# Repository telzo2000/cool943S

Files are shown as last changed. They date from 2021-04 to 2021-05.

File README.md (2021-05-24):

# ビルドガイド（執筆中）
https://github.com/telzo2000/cool943S/blob/main/buildguide_for_cool943S.md
<br>

# cool943S開発計画
☑︎アクリルケースの設計<br>
☑︎ファームウェアの用意<br>
<br>

# 発注ガーバーファイル名
Ver.1　gbrcool943S20210212.zip,cool943Scasedesigntop.zip,cool943Scasedesignbottom.zip　<br>
Ver.1.1 gbrcool943S20210314.zip <br>
<br>

# cool943S開発に至った経緯

cool943Sは、m.ki設計の自作キーボードです。cool836Aの次の自作キーボードとして、三桁の数字の左はじめに９が付きます。その次の二桁には、採用されたキー数として43と付きます。末尾のSはSplit（分割型）を意味しています。「coolな９番目の43キーある分割型キーボード」となります。<br>
構成はPCBを、いつも便利なSU120で作っています。ケースは全体を覆うようにMDF材を塗装しています。安価な材料としてMDFは優秀です。底面は内部が見えるように、アクリルプレート（スモークガラスのようなもの）を使っています。これらの構成は、これまでキーボードを自作した経験から選択したものであり、一般的な自作キーボードの作り方ではないかもしれません。<br>
cool943S開発の目的は、アドベントカレンダー2020に記事を投稿しようということから始まりました。<br>
そのため、これまで自分が挑戦したことがないものを作ろうと思い、40％の分割型キーボードを選択しました。nomu30を購入して30％キーボードの潔さに影響を受けて、自分でも令和2年上半期に30％キーボードMyFirstMini（34キー）を作りました。この際、SU120を初めて使いました。
MyFirstMiniはnomu30を常用した自分に、ちょっと困った句読点記号のキーを独立して配置しました。nomu30ではレイヤーキーとして使われている句読点記号キーは、日本語入力が主体の私にはちょっと利便性が抑えられました。
その後、購入したCaravelle bleの余剰パーツを利用したCarabellionを作り、SU120の使い方や、木製ケースの組み合わせ方を経験しました。
Carabellionと並行して、格子配列のcool635も開発しました。cool635は35キーの30％キーボードでPro microの配置を考えてキーレイアウトをしました。その後、配線処理に苦労して、ポリウレタン銅線から、シリコンケーブル線に変更するきっかけとなりました。cool635によって、私にとって10列で構成されるキーボードはちょっと使い勝手が難しいこともわかりました。
特に、Pキーの左隣にはBSキーが欲しいことがわかりました。<br>
ここまで作っていくと、30％キーボードでだいたい、問題はないことがわかりました。しかし、矢印キーや数字キーがあったら、やはり便利だろうと思い、30％キーボードのレイアウトに、矢印キーと数字キーを加えた構成で、cool735を開発しました。ただ、cool735は悪くないのですが、やや大きくなり持ち運ぶという用途には向かないキーボードです。常用できないのではしかたがないので、作ってみたけど、お蔵入りの品物となりました。Carabellionも同様に、お蔵入りしています。原点回帰というわけではありませんが、MyFirstMiniの延長上に、30％で使いやすいキーボード、余り肩を狭めない配列としてアリス配列を採用する、というコンセプトから、cool836Aを開発しました。<br>
cool836Aについては、cool836Aの[README](https://github.com/telzo2000/cool836A/blob/master/README.md)に詳しく記録してあります。<br>
cool836Aの欠点は、キー数です。持ち運びを考えたとき、あの大きさは有利であり、キーレイアウトは疲れを軽減すると思います。ただ、あれ以上のキー数を求めたとき、40％のAlice配列のキーボードが必要となります。ただ、それは大型化を招き、結果的に、一般的なAlice配列のキーボード（60％や65％）に帰結すると思います。私の中では40％のAlice配列は持ち運び用途としては大きい印象です。その大きさでAlice配列を求めるのであれば、分割キーボードで十分と考えます。ここからcool943Sのコンセプトは決まりました。<br>
Alice配列ではないけど、肩を狭めなくても良い分割型、そして40％キーボードとなりました。<br>
課題はただ一つ、私自身が分割型キーボードを開発した経験がないことでした。これまで作ってキーボードでは、ファームウェアの開発はせずにすみました。Keyboard Firmware Builderというサイトが、初心者の私の味方でした。しかし、このサイトでは多分、分割型キーボードのファームウェアは作れないのです。（私が使い始めた頃は、LED関係の機能もできませんでしたが、令和２年秋ごろにはできるようになりました）<br>
結果として、私はこれまで回避してきたqmk_firmwareの勉強をする羽目となりました。私が普段使っているのはマックです。先人たちの情報をネットで探しながら、やってみましたが、できません。homebrewあたりからつまずきました。pythonがいろいろと邪魔をして、先へ進めませんでした。<br>
我が家にあるMacOS以外のOSを持つコンピュータは、ラズパイとGPD Pocket2でした。ウインドウズはさらにわからなかったので、ラズパイでなんとかすることとしました。ネットで「ラズパイ」「QMK」で検索かけたら、いくつかサイトがヒットしました。それらを順に見て、バタバタしていたら、12月末、ラズパイでqmk_firmwareが使えるようになりました。そこでまず、KEYBOARD FIRMWARE BUILDERでファームウェアを作って動かしていていたcool836Aを元にして、qmk_firmwareで作り直すことに成功しました。すぐにできたのではなく、他の人のファームウェアを真似して出来上がったものです。その経験を元にして、cool943Sのファームウェアを作り始めました。元にしたのは、keebioのfourierとRecompile Keyさんのcocoa40です。元々、この２つの分割40％キーボードがcool943Sの目指した姿だったのです。実際のところ、キー数は少なくしてあります。私自身、30％キーボードを常用しています。キー数が少なくても問題はありません。cool943Sは40%のアリス配列の代わりに、より使いやすい配列として分割キーボードを選択して生まれたものです。fourierやcocoa40を入手できていたならば、自分で作ることはなかったと思います。今のところ、cool943Sは私にとってのエンドゲームかもしれません。<br>
令和元年に購入して以来、職場に持ち込み、1年と少しの期間使用していたChoco60に代わって、cool943Sを職場に持ち込みました。職場で使用して問題がなければ、自宅用にもう一つ、作成しようと考えています。（とりあえず、ここまで　令和３年１月27日）<br>
令和3年2月12日にelecrowへkicadで設計したcool943Sを発注しました。アクリルケースも一緒に発注しました。ただ春節絡みで届くのが遅くなりました。<br>
2月末にelecrowから発注していたPCBやアクリルが届きました。しかし検品の段階で、アクリルは注文通りでないことがわかり、メールで修正するように伝えました。
届いた部品のうち、ミドルプレートが注文通りでなく、左右と長さの違う形状で４種類のミドルプレートを注文していたが、同じ形状のものでした。
多分、担当者がよく見ずに、似ていると思い込んで、同じものを複数枚作成したと思われる。
これは相手側のミスであったため、さらに数日後、正しいものが届くまで完成が待たされた。　<br>
実際に作ってみたときにわかった問題点は次の通りである。<br>
①三行目左端のシフトキー部分のスイッチ位置のミス。これについてはkicadで修正した。<br>
②通信に関するピンサインのミス。今後、kicadで修正した。<br>
③混線が発生している可能性。原因がわかっていない。kicadで確認する。②の修正により解決すると思われる。<br>
④アクリルで作ったスイッチプレートが割れやすいこと、スイッチを装着しづらいこと。スイッチプレートをPCBと同じ素材で作るか、スイッチプレートとPCBの間に３mmのアクリルプレートを挟むか、３mmスペーサーを付け加えるか、が思いつく対応策。<br>
上記の①～④を修正したPCBをVer.1.1とした。３月14日elecrowに発注。これは、以前アクリルで作成したスイッチプレートをPCBと同じFR-4素材で作成した。結果として、Ver.1のPCBとスイッチプレートと差し替えることで、Ver.1の資産を継続して使えるようにした。これにより問題なく活用できるようであれば、全部で５セット分ある部品のうち、すでに作成した１セットと、予備用に１セットを残して、他３セットを頒布しようと考えている。これはcool844ほど反響がないと思っているので、それ以上の追加発注は考えていない。<br>
3月末に、ver1.1を組んでみた。FR-4で作ったスイッチプレートはアクリルで作ったものに比べて、剛性感が高かった。強度の心配はなくなった。elecrowに発注した部品は一箇所、ミスがわかり、後日修正されたものが届くこととなった。誰かが春節すぎると技術が低下すると言っていた。そうなのかもしれない。でも、時間がかかるが、修正版が届くのでまあ、よい。このあと、LEDテープを貼り付けて、LEDの点灯もできた。キーレイアウト編集のために、REMAPが使えるようにした。これで初心者でもキーレイアウトの編集が容易になる。<br>
また、４月になり、修正されたスイッチプレートelecrowから届いたので、２台目のcool943Sを作成した。
これはキースイッチをT3 タンジェリンで組み、今年になって職場に持っていったSU120版cool943Sと交換した。
kicad版cool943Sを２台作り、わかったことは、発注したアクリルは２mmであるが、実際はやや２mmより薄いのであろう。
そのため、ミドルプレートに４枚アクリル板を積層し、固定するために入れた８mmスペーサーがやや頭が出ている状態である。
これについては、７mmスペーサーを発注して、対応してみようと考えている。<br>
④の問題点の解決策として、PCBと同じFR-4でスイッチプレートを作った。
そのため、アクリルでのスイッチプレートは不要である。
しかし、アクリルのスイッチプレートを作っても作らなくても、使用するアクリル板の大きさは変わらないことがわかった。
結果として、被ってしまうが、①の問題点と、割れやすい箇所のやや広く作ったアクリル板のスイッチプレートの修正をした。<br>
アクリルケースについては、４月１８日時点では発注しない。最初の３台の頒布をして、その後、まだ欲しい人がいるようであれば、その時発注しようと思う。<br>

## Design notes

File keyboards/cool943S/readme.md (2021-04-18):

# cool943S

cool943S

*A short description of the keyboard/project*

* Keyboard Maintainer: [m.ki](https://github.com/telzo2000)
* Hardware Supported: *The PCBs, controllers supported*
* Hardware Availability: *Links to where you can find this hardware*

Make example for this keyboard (after setting up your build environment):

    make cool943S:default

Flashing example for this keyboard:

    make cool943S:default:flash

See the [build environment setup](https://docs.qmk.fm/#/getting_started_build_tools) and the [make instructions](https://docs.qmk.fm/#/getting_started_make_guide) for more information. Brand new to QMK? Start with our [Complete Newbs Guide](https://docs.qmk.fm/#/newbs).

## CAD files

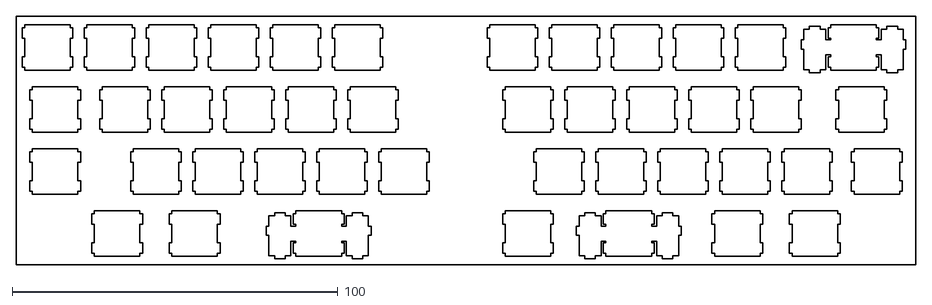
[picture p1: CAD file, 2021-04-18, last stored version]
a34305ff9da19b46c51bc98033632a78f7ae009a_switch.dxf
276.2 x 76.2

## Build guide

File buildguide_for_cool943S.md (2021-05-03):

# cool943S　ビルドガイド
## 特徴
<br>
・cool943Sは、m.kiが設計した40％分割キーボードです。
40％分割キーボードはあまり多く流通していません。自分用に欲しいと思い、これまで自作したcool836A、cool844等得た経験を生かして設計しました<br>
・入力に必要なキー以外を省略することでコンパクトな形にしました。<br>
・pro microの配置位置を工夫することで、高さを抑えました。
私はcool943Sを使用する際、パームレストは不要となりました。<br>
・トップカバープレートにより、pro microに置き換えて、将来的にble microと電池ケースを使用することも構造的に可能となっています。
・ファームウェアは、youichiro氏の開発したREMAPにて、キーレイアウトの編集が簡単にできます。
QMK_FIRMWAREの知識が無くても大丈夫です。<br>
・サウンドテストの様子<br>
https://twitter.com/0002ozlet/status/1381212035929665536
<br>

## 1　部品の確認
次の部品で構成されています。<br>
１　　PCB　左右それぞれ１枚<br>
２　　スイッチプレート　左右それぞれ１枚<br>
３　　トップカバープレート　左右それぞれ１枚<br>
４　　ミドルプレート　左右それぞれ４枚<br>
５　　ボトムプレート　左右それぞれ１枚<br>
６　　チルトプレート　左右それぞれ２枚<br>
７　　M２ネジ（４ｍｍ８本、８ｍｍ12本）<br>
８　　M２ナット　６個<br>
９　　M２スペーサー８ｍｍ六角形タイプ　10個<br>
１０　Pro micro　２個<br>
１１　TRRSジャック　２個<br>
１２　タクトスイッチ　２個<br>
１３　TRRSケーブル １本<br>
１４　MXソケット　43個<br>
１５　ダイオード　43個<br>
１６　LEDテープ　２枚<br>
１７　スタビライザー（２Uサイズ）　３個<br>
１８　キースイッチ　43個<br>
１９　キーキャップセット　※任意<br>
２０　USBケーブル（Pro microの端子に準拠したもの）<br>
２１　ゴム足（クッションゴム、ウレタンパッドなど）<br>
<br>
部品のうち、<br>
１〜６はキットに同封されています。<br>
７・８・２１はDIY店でも購入可能です。<br>
９は遊舎工房またはWILCOでネット通販可能です。４のミドルプレートの厚さについてアクリルの精度に課題があり、隙間なく重ねたとき、M２スペーサー８mmがやや出てしまうことがわかりました。気になる方は、M２スペーサー７mm六角形タイプ８個も用意することを勧めます。<br>
１０〜２１は遊舎工房、TALP KEYBOARDS、KOCHI KEYBOARDで店頭もしくはネット通販で購入可能です。<br>
これらの部品を、すべてを同封してキット化することできないため、購入者が別途に購入する必要があります。
そのため、私自身が設計、発注した部品１〜６のみ、頒布する形を取りました。
それにより、私自身、部品等を余剰に在庫する必要もなく、購入者自身も選択肢のある部品等を自分の好みで購入することができ、お互いにとって、良い形になると思います。

<br><br>

部品の写真（１・２）
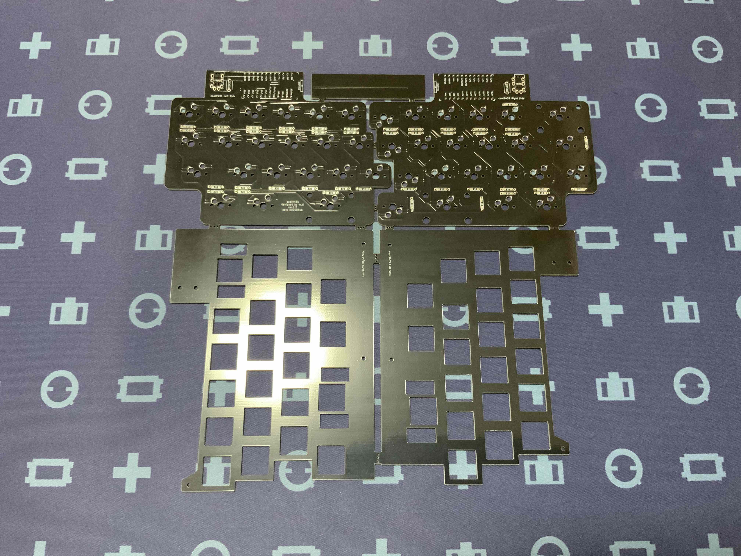
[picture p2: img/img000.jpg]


部品の写真（３・４・５・６）
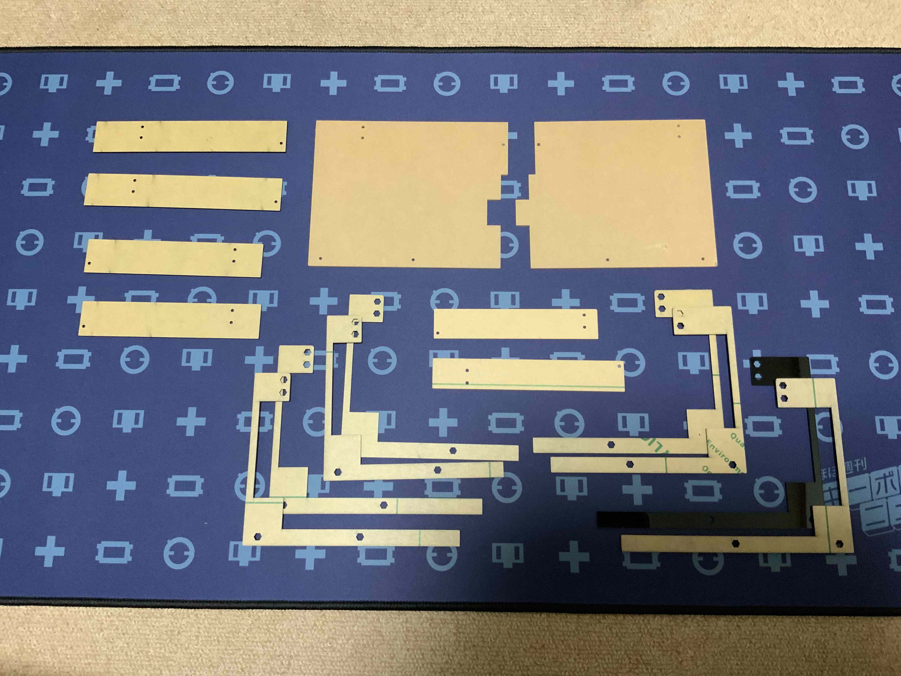
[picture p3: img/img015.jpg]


## ２　ファームウェアについて
cool943Sはyouichiro氏の開発したREMAPにて、キーレイアウトの編集ができます。<br>
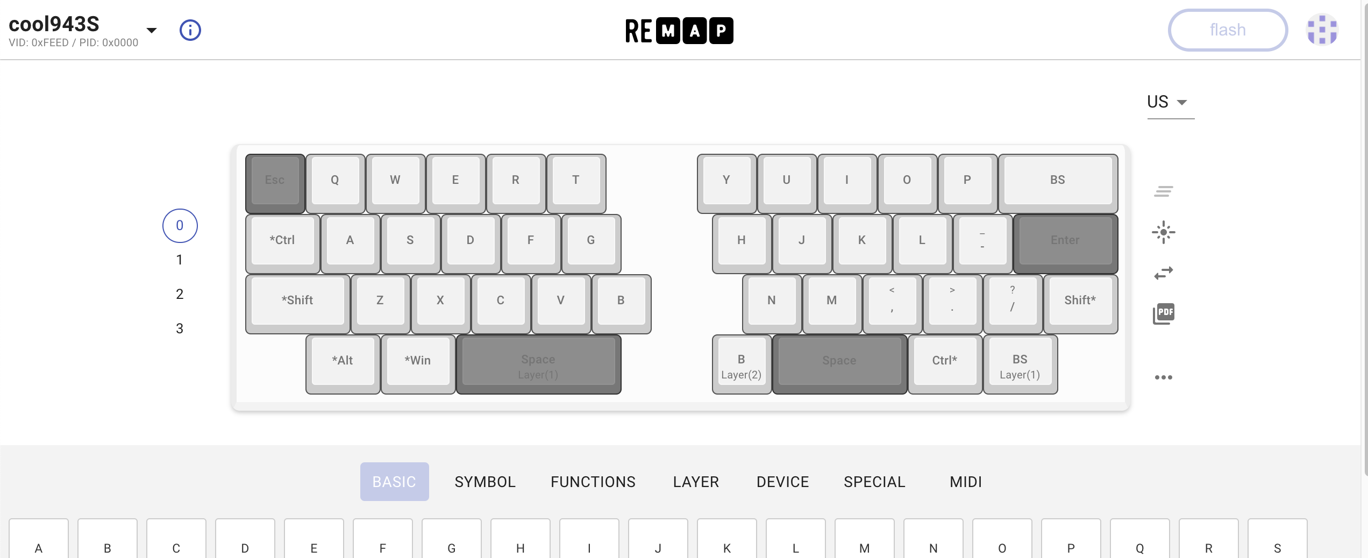
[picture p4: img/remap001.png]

次の[Hexファイル](https://github.com/telzo2000/cool943S/blob/main/cool943S_via.hex)をダウンロードしてください。そして、QMK TOOLBOXにてPro microへの書き込みをしてください。<br>
REMAPで作業するための[Jsonファイル](https://github.com/telzo2000/cool943S/blob/main/cool943S_remap.json)はこちらにあります。<br>
chromeを起動して、「REMAP」と検索し、REMAPのサイトへアクセスしてください。<br>
（令和3年５月３日追記）REMAPに正式対応しました。
申し込みから承認までの素早い対応に感謝します。<br>
（追記終了）<br>

## ３　色塗り
スイッチプレート及びPCBの側面を黒色マジックで塗ってください。cool943Sは側面が黒色アクリルプレートを使用していますので、スイッチプレート及びPCBの側面も同じ黒色のほうが格好良くなります。<br>
## ４　ダイオードのハンダ付け
ダイオードの足を曲げて取り付けて、ハンダ付けをします。ダイオードの足は、下面から「diode」と印刷された部分の穴に差し込みます。短く切ったマスキングテープで固定してから、裏返して、上面に伸びたダイオードの足は切り離してください。ダイオードには極性があります。ダイオードの黒い帯がある側が「diode」の文字の後ろになるようにハンダ付けしてください。ハンダ付けに自信がない場合、フラックスを利用すると、上手にハンダ付けができます。その後、フラックスクリーナーで綺麗に拭き取ることをお勧めします。<br>
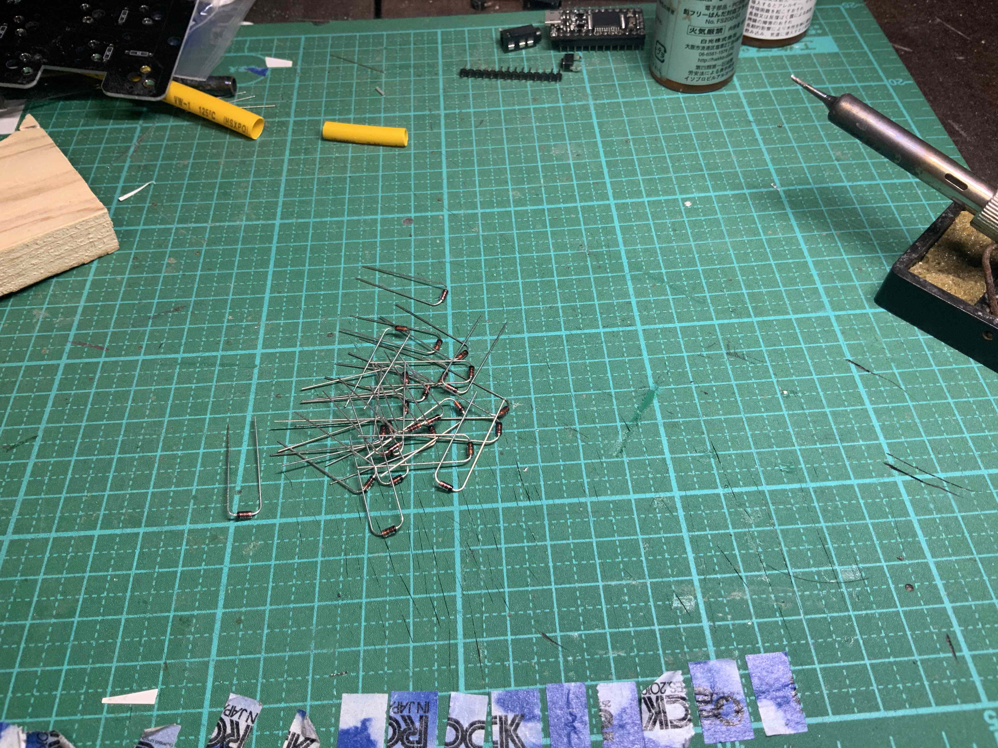
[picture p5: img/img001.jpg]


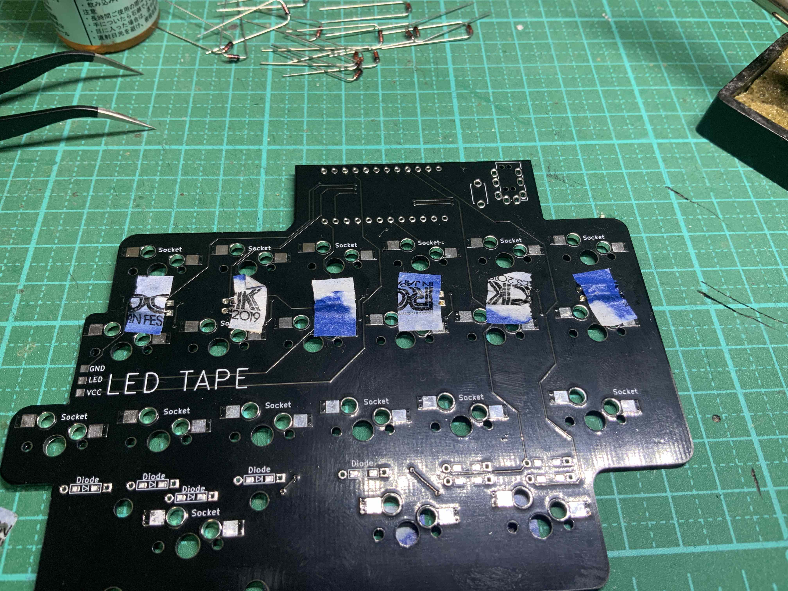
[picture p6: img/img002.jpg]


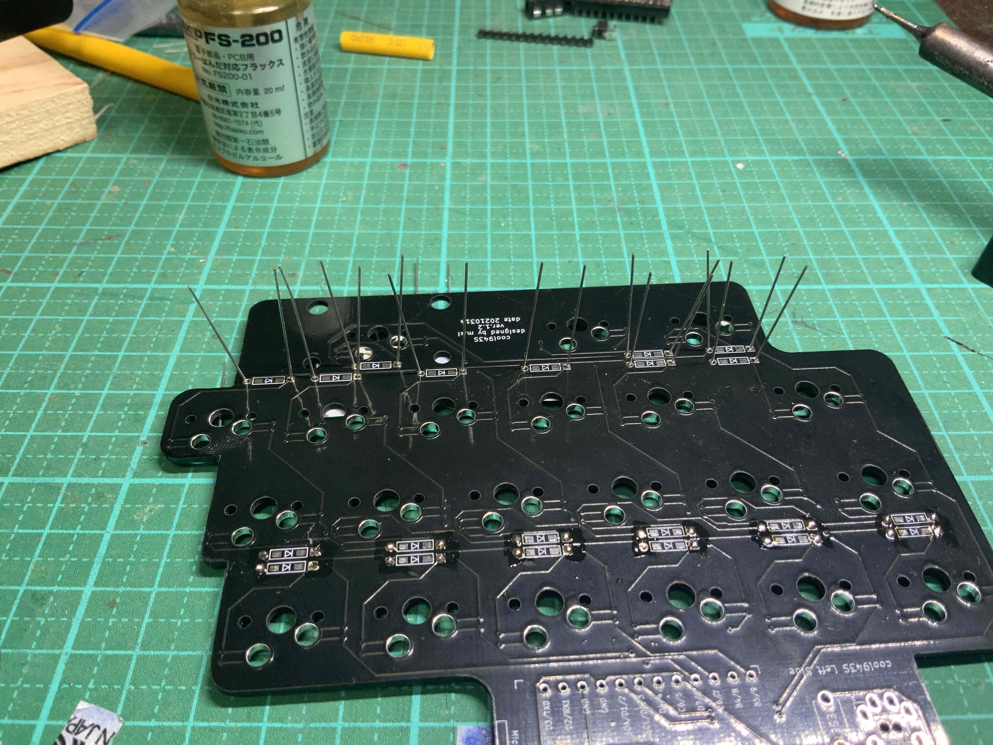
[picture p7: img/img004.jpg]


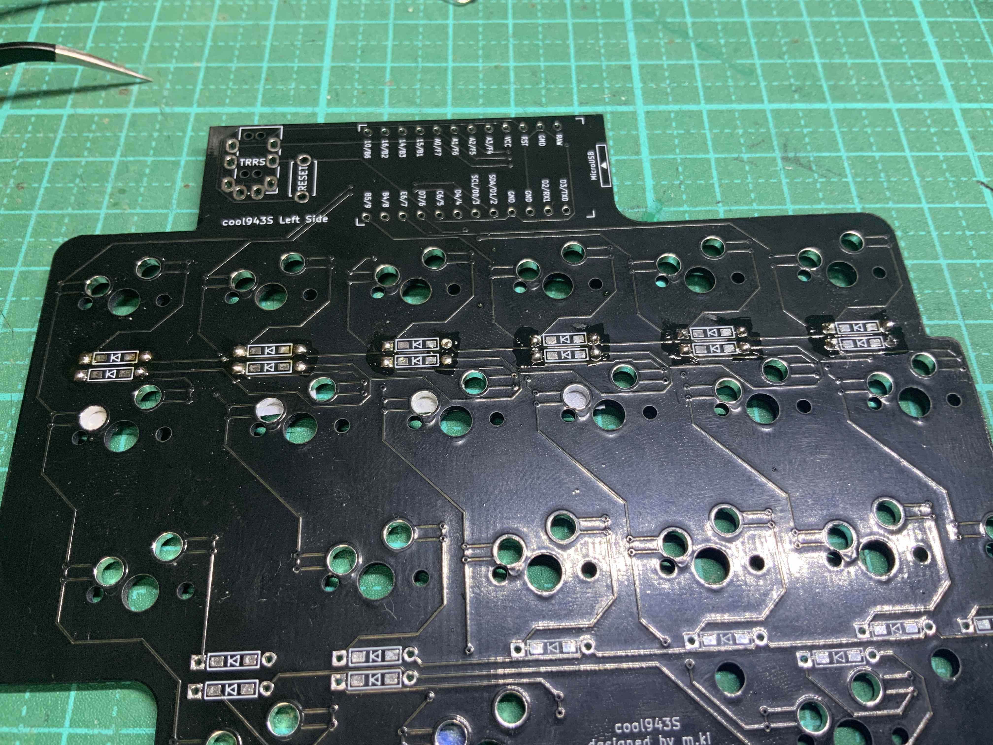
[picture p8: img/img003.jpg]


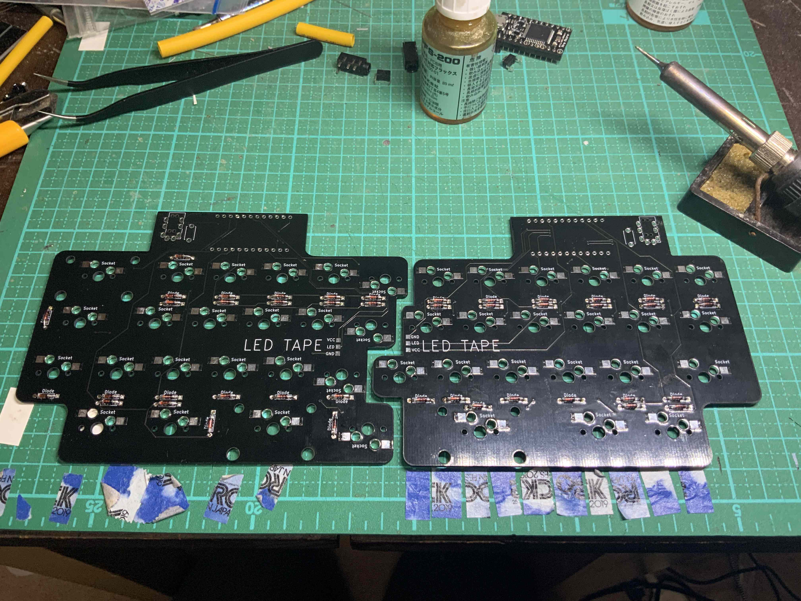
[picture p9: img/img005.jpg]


## ５　MXソケットのハンダ付け
MXソケットをハンダ付けします。ソケットの向きに注意してください。基板にはSocketと書かれています。文字が隠れるようにソケットを置いてください。ソケット両側の端子がPCBと接する方に、予備ハンダをしておくと、ハンダ付けが上手くいきます。上手くハンダ付けができない場合、フラックスを多めに塗布して行うと、ハンダがソケットの端子とPCBの端子の間に流れていきます。その後、フラックスクリーナーで綺麗に拭き取ることをお勧めします。<br>
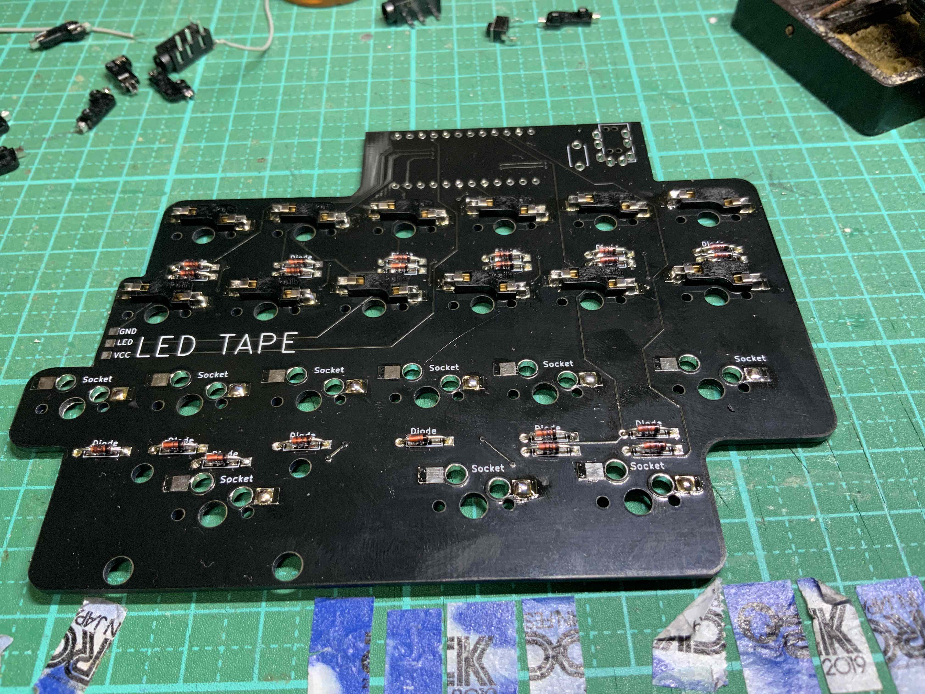
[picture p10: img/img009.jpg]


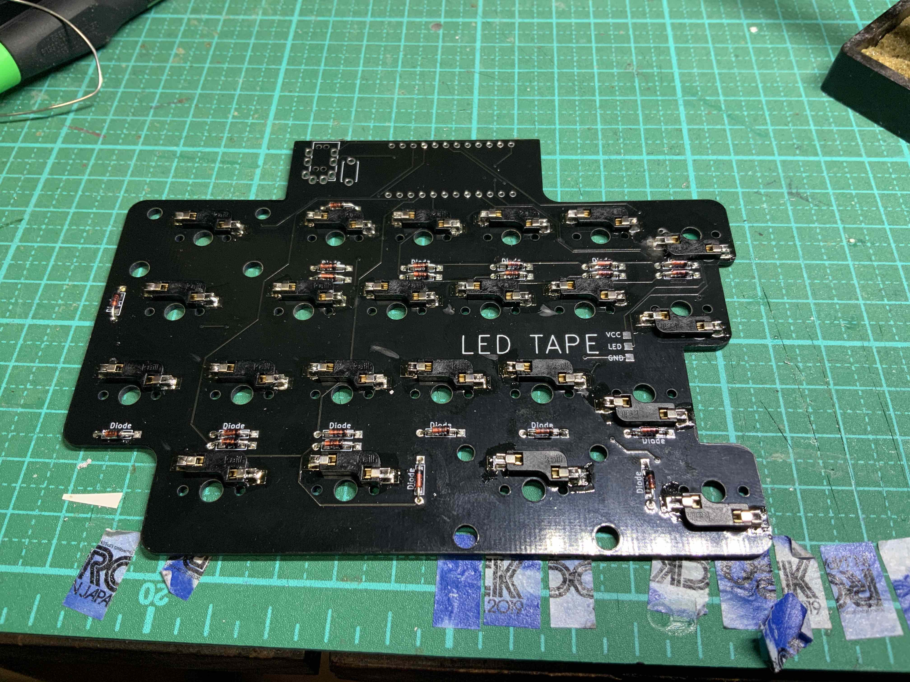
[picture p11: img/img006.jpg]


## ６　タクトスイッチのハンダ付け
タクトスイッチをPCB上面の「RESET」の印刷が隠れるように差し込んで、下面からハンダ付けをしてください。ここは上・下面を間違えると、後でトッププレートをつける時に、タクトスイッチが干渉します。タクトスイッチは左右それぞれに付けます。<br>

## ７　TRRSジャックのハンダ付け
TRRSジャックをPCB上面の「TRRS」の印刷が隠れるように差し込んで、下面からハンダ付けをしてください。ここは上・下面を間違えると、後でトッププレートをつける時に、TRRSジャックが干渉します。TRRSジャックは左右それぞれに付けます。<br>

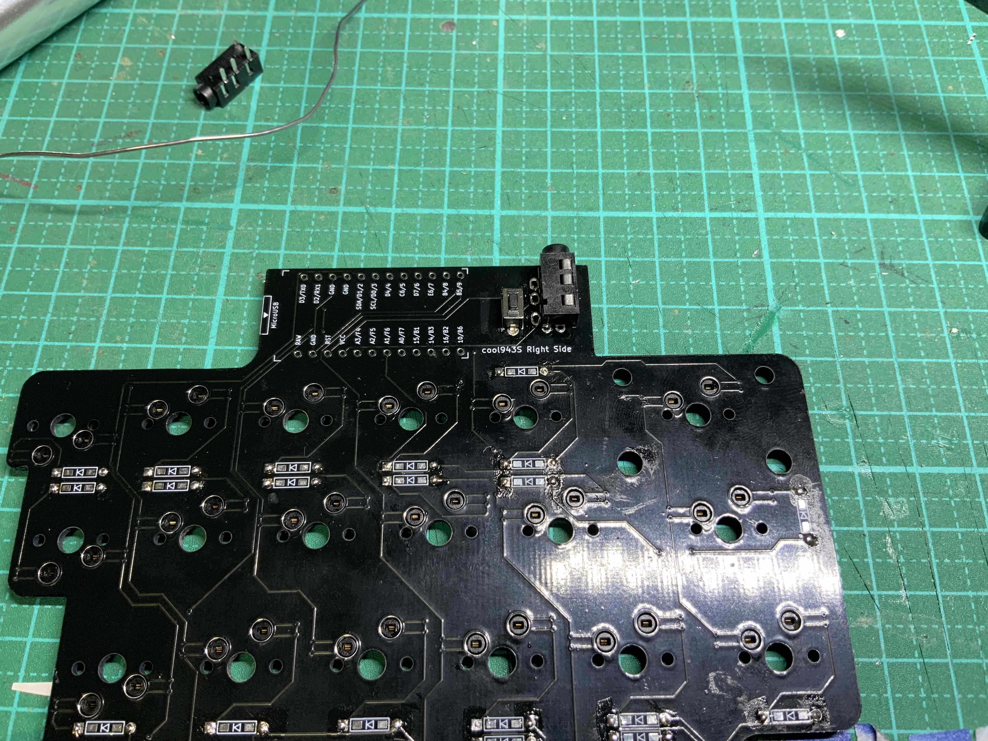
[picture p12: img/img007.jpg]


## ８　LEDテープのハンダ付け
ver.1.1では、LEDテープとPCBの端子部分がややずれています。ダイオードの切り取った足を使ってつなげて対応してください。先にLEDテープの裏紙を剥がしてPCBに貼り付けてから、ハンダ付けをしてください。<br>
LEDテープの取り付けは任意ですので、光らせることに興味がない場合は、装着しなくてもキーボードとしての機能に問題はありません。しかし、光らないよりは光るほうが、キーボードは格好良く見えます。LEDテープを装着することを推奨します。<br>

## ９　pro microの取り付け
　本製品ではコンスルー（スプリングピンヘッダ）を使用してのpro microの装着を推奨しています。コンスルー（スプリングピンヘッダ）の向きに気をつけて使用してください。pro microに装着している面が下に向くように（PCBに向くように）してください。pro microは左右それぞれに付けます。
 
## １０　動作確認
ここで一度、動作確認をすることをお勧めます。pro microにファームウェアを入れて、仮にキーキャップをソケットに差し込んで、キースイッチを打鍵した時に反応するかどうか、確認してください。打鍵したけど、入力されない時は、ダイオードの向きが間違っていないか、ソケットのハンダ付けが外れていないか等が原因になります。テスターで導通を確認してください。入力確認には、次のサイトがお勧めです。<BR>
  https://keyboardchecker.com
 <br>

## １１　スタビライザーの取り付け
事前にスタビライザーは、ルブ（グリスを塗布すること）をしておきましょう。ルブしていないと打鍵したときに、かちゃかちゃとした金属音がちょっと残念な気持ちにさせます。<br>
スタビライザーについては、最近、国内外を問わずに、安価なものから、それなりに良いものまで入手できます。そのため、本キットでも別途、購入としています。ただ、購入する際は、PCBに直付けするタイプのスタビライザーを選んでください。
<br> 

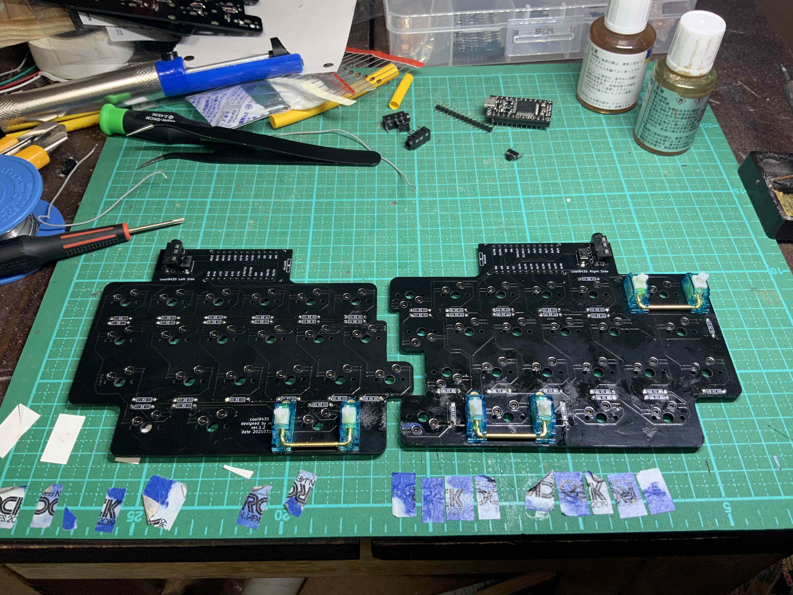
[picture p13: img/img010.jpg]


## １２　キースイッチの取り付け
　最初にキースイッチ４個ほどをトッププレートの四隅等４箇所に差し込みます。一度に全部のキースイッチを取り付けて、その後にPCBにハンダ付けしたMXソケットに差し込むとうまくいかないことが予想されます。４箇所で一度PCBにハンダ付けしたMXソケットに差し込み、残りのキースイッチをトッププレート、PCBの順に差し込んでください。それぞれのキースイッチの足がきちんとMXソケットの基板の穴に差し込まれていることを確認してください。差し込むときに、足が曲がってしまうことがあります。その場合は、ボタンを押しても入力されません。一度キースイッチを外して、足の修正または新しいキースイッチに交換等対処してください。 <br>
出来上がったものは、次の作業工程13の④でケースに装着します。<br>

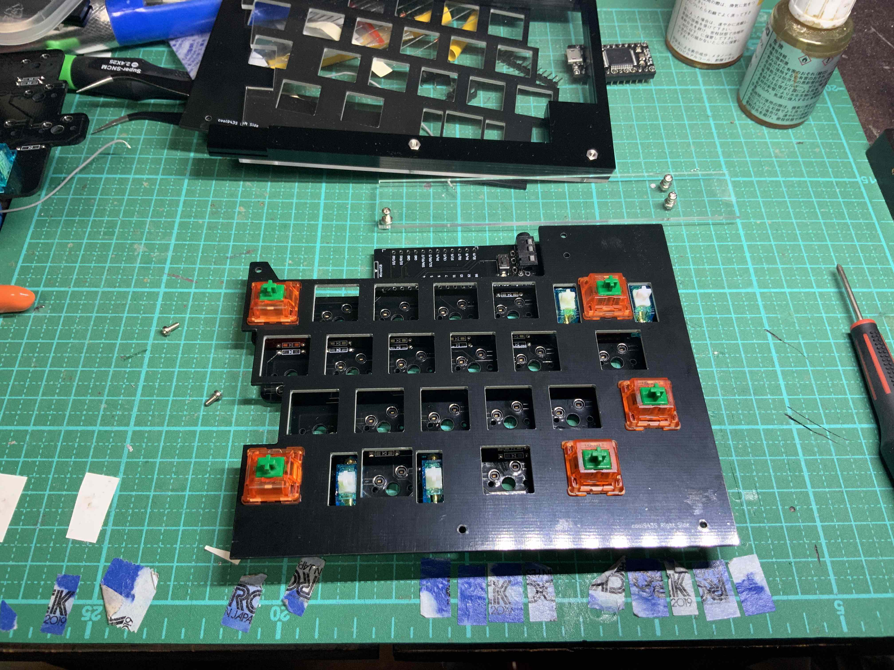
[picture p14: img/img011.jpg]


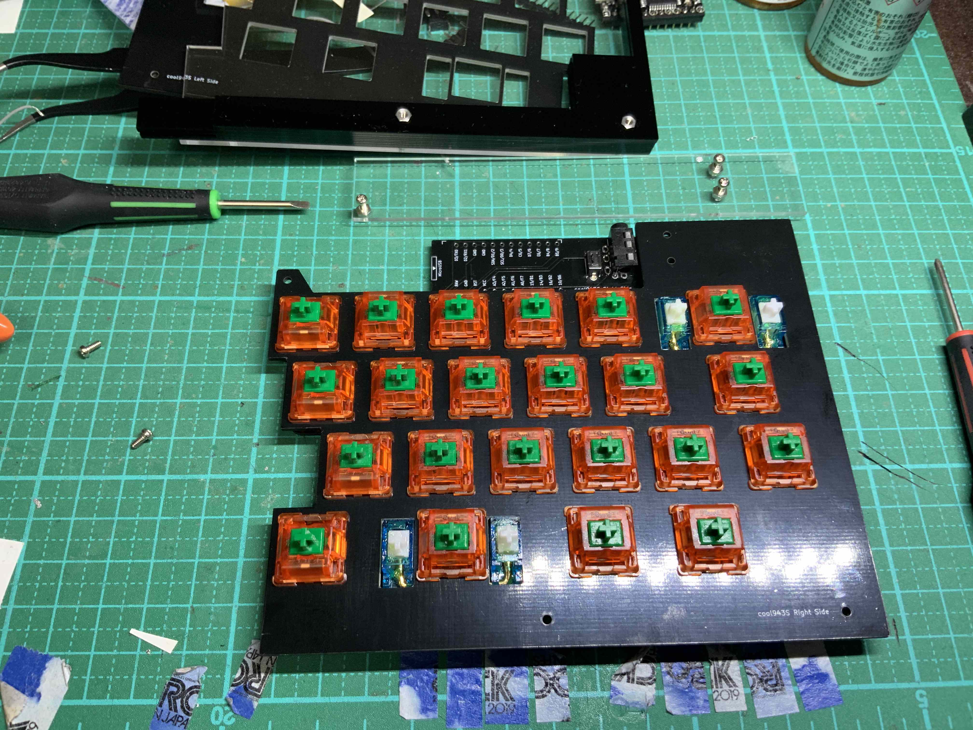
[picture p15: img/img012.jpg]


## 13　ケースの組み立て
最初に、手を石鹸で洗いましょう。その方が手の脂がアクリルに付着啜るのを防げます。次にアクリルの保護紙を剥がしてください。<br>
①ボトムプレートとチルトプレートを組み立てます。M2ネジ８mmをチルトプレート側から差し込み、反対側ではM2スペーサー８mmで止めます（ここでは緩めに締めてください）。<br>
②チルトプレートと重ならない箇所（左右それぞれ手前側の２箇所）は、M2ネジ４mmを下面から差し込み、反対側ではM2スペーサー８mmで止めます（ここでも緩めに締めてください）。
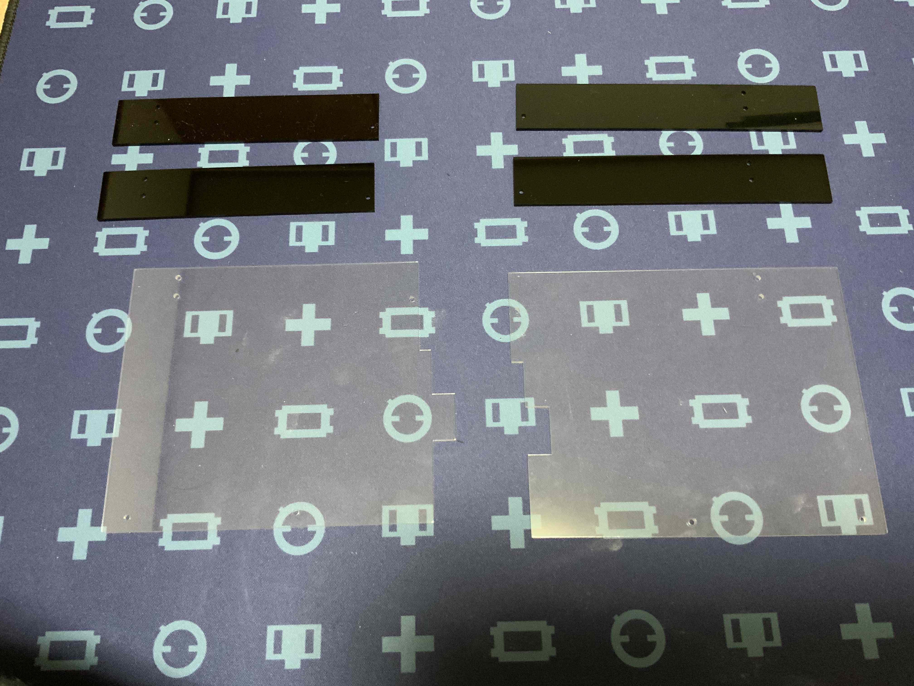
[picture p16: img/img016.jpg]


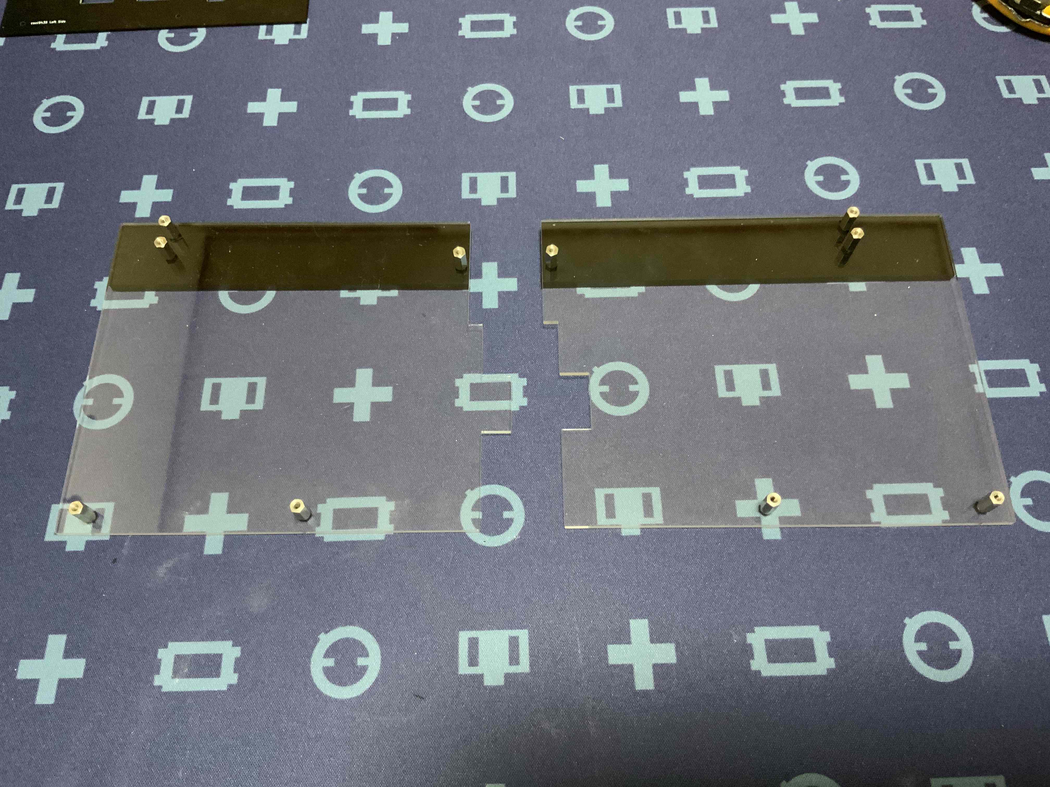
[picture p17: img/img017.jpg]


③左右それぞれに、ミドルプレート４枚を重ねていきます。ミドルプレートは左右それぞれに、大きさの違うものが２枚ずつあります。見分け方は、左右それぞれに親指がくるあたりの長さが違います。この部分を、例えば、右側のミドルプレートが短いものときは、左側のミドルプレートは長いものとする。次に右側のミドルプレートが長いもののときは、左側のミドルプレートを短いものとする。このように違い違いにしながら、ミドルプレートを重ねていってください。①・②で緩めに締めM2スペーサーの六角形とミドルプレートの六角形の切り抜きとがうまく入るように調整しながら重ねてください。<br>

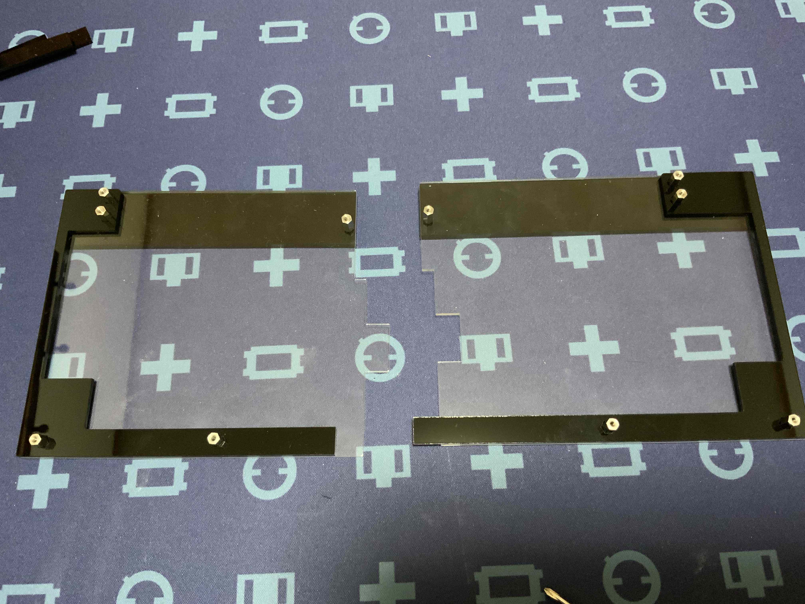
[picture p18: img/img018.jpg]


④スイッチプレートをケースに装着します。左右それぞれケース手前２箇所は、M2ネジ４mmで締めます。

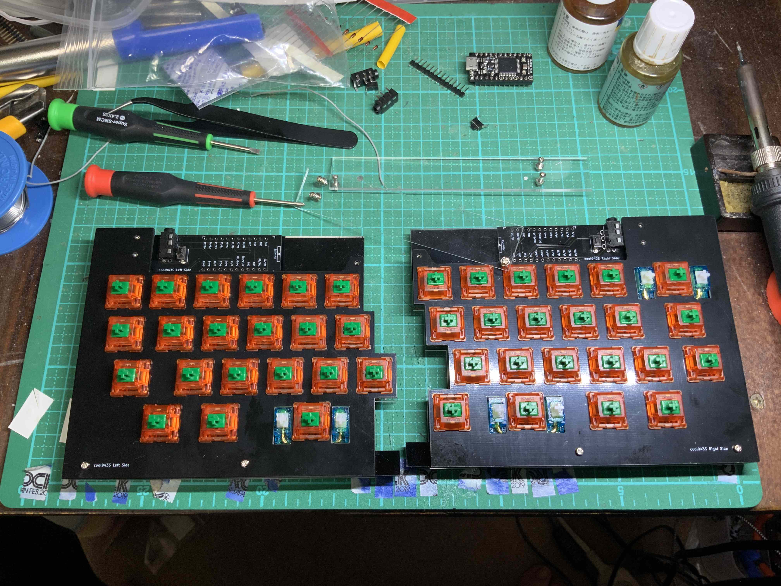
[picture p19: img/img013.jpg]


⑤トップカバープレートを装着します。トップカバープレートは左右長さが違いますので、装着する前に確認してください。
トップカバープレートの上面からM2ネジ８mmを差し込みます。
反対側（トップカバープレートの下面）でM2ナットを通してから、スイッチプレート上面に差し込んでいきます。<br>
トップカバープレートとスイッチプレートの間に、M2ナットを挟むことで、PCBの上面に差し込まれているpro microがトップカバープレートと接触しないようにしています。<br>
この構造は将来的に、pro microの代わりに、ble micro（ブルートゥースが使えるpro micro）を使用することを想定しています。
その際、M2ナットの代わりに、必要な高さのM2スペーサーに交換することで、電池ケースまで合わせて装着することができます。<br>

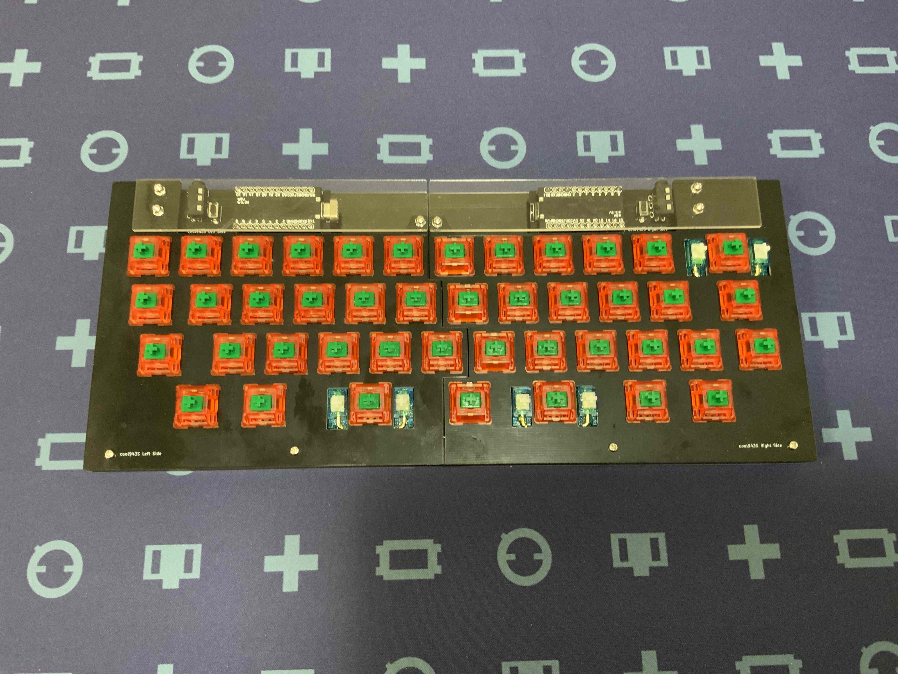
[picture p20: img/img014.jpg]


PCBを収納していない仮組み状態でケースを組み立てもの<br>

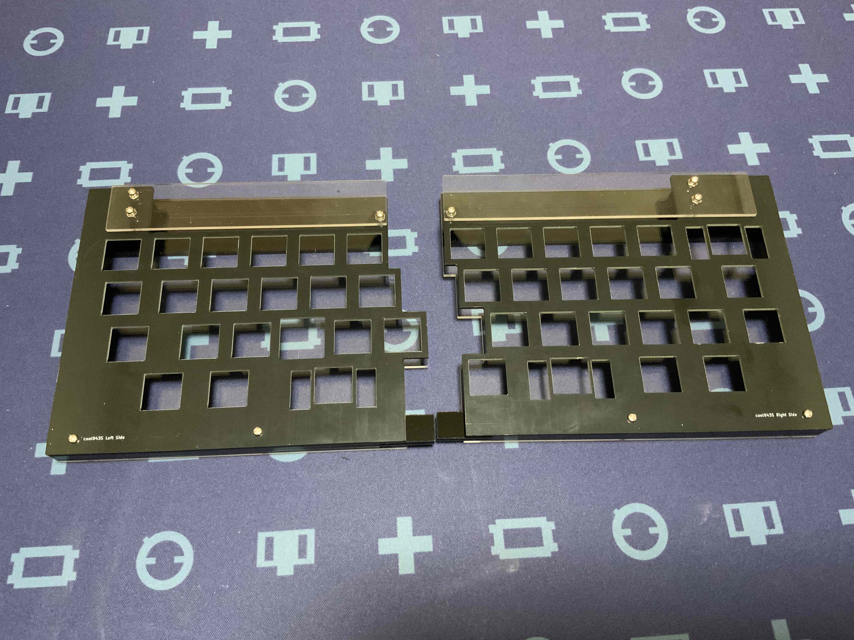
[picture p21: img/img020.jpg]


## 14　キーキャップやゴム足の装着
ご希望のキーキャップを装着してください。
本キーボードでは、例えば1.75Uのエンターキーなどはベースセットでそろえられず、40%キットが必要となります。
<br>
ゴム足は、左右それぞれ４箇所、合計８個必要となります。<br>
<br>

## 15 完成
USBケーブル、左右を繋ぐTRRSケーブルを装着して完成となります。<br>
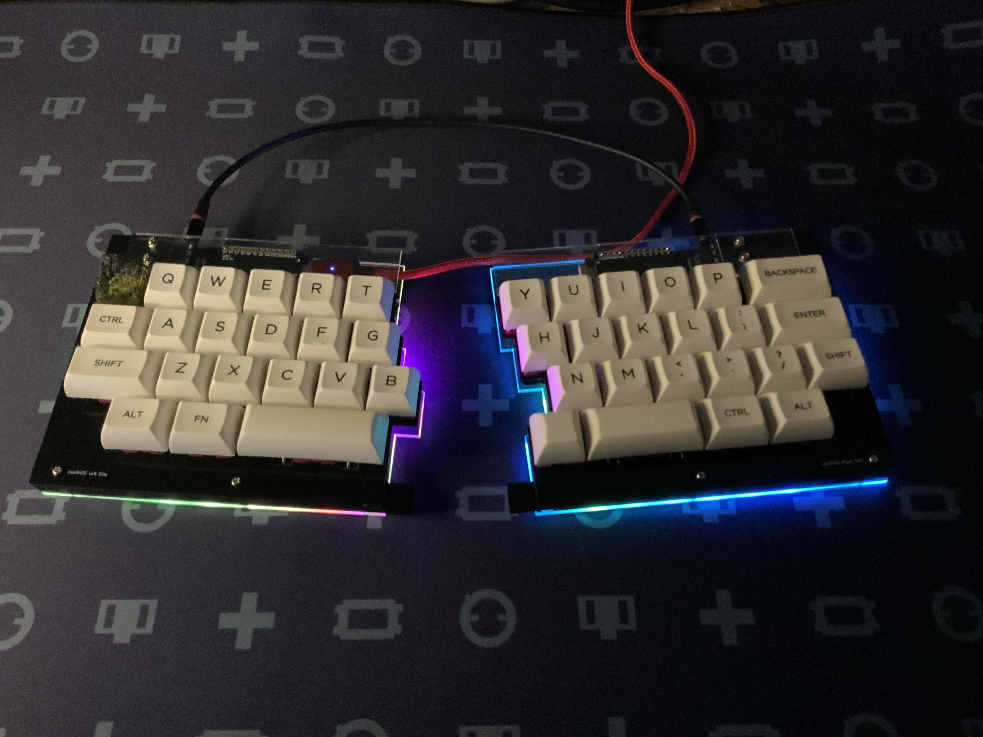
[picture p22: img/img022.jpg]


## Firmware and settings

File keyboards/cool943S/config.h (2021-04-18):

/*
Copyright 2020 m.ki

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
You should have received a copy of the GNU General Public License
along with this program.  If not, see <http://www.gnu.org/licenses/>.
*/

#pragma once

#include "config_common.h"

/* USB Device descriptor parameter */
#define VENDOR_ID    0xFEED
#define PRODUCT_ID   0x0000
#define DEVICE_VER   0x0001
#define MANUFACTURER m.ki
#define PRODUCT      cool943S
#define DESCRIPTION     Split 40 percent staggered keyboard

/* key matrix size */
#define MATRIX_ROWS 8
#define MATRIX_COLS 6

/*
 * Keyboard Matrix Assignments
 *
 * Change this to how you wired your keyboard
 * COLS: AVR pins used for columns, left to right
 * ROWS: AVR pins used for rows, top to bottom
 * DIODE_DIRECTION: COL2ROW = COL = Anode (+), ROW = Cathode (-, marked on diode)
 *                  ROW2COL = ROW = Anode (+), COL = Cathode (-, marked on diode)
 *
 */
#define MATRIX_ROW_PINS { F6, F7, B1, B3}
#define MATRIX_COL_PINS { D1, D0, D4, B5, D7, E6 }
#define UNUSED_PINS

/* COL2ROW, ROW2COL */
#define DIODE_DIRECTION COL2ROW

/*
 * Split Keyboard specific options, make sure you have 'SPLIT_KEYBOARD = yes' in your rules.mk, and define SOFT_SERIAL_PIN.
 */
#define SOFT_SERIAL_PIN D2  // or D1, D2, D3, E6

//#define LED_NUM_LOCK_PIN B0
//#define LED_CAPS_LOCK_PIN B1
//#define LED_SCROLL_LOCK_PIN B2
//#define LED_COMPOSE_PIN B3
//#define LED_KANA_PIN B4

//#define BACKLIGHT_PIN B7
//#define BACKLIGHT_LEVELS 3
//#define BACKLIGHT_BREATHING
//#undef RGBLED_NUM
//#define RGB_DI_PIN E2 ここをいじる。ピンの名称を確認。
//#ifdef RGB_DI_PIN　ここをいじる。
//#    define RGBLED_NUM 10　ここをいじる。836では６を入れている。
//#    define RGBLIGHT_HUE_STEP 8　ここをいじる。
//#    define RGBLIGHT_SAT_STEP 8　ここをいじる。
//#    define RGBLIGHT_VAL_STEP 8　ここをいじる。
//#    define RGBLIGHT_LIMIT_VAL 255 /* The maximum brightness level */
//#    define RGBLIGHT_SLEEP  /* If defined, the RGB lighting will be switched off when the host goes to sleep */
/*== all animations enable ==*/
//#    define RGBLIGHT_ANIMATIONS　ここをいじる。
/*== or choose animations ==*/
//#    define RGBLIGHT_EFFECT_BREATHING
//#    define RGBLIGHT_EFFECT_RAINBOW_MOOD
//#    define RGBLIGHT_EFFECT_RAINBOW_SWIRL
//#    define RGBLIGHT_EFFECT_SNAKE
//#    define RGBLIGHT_EFFECT_KNIGHT
//#    define RGBLIGHT_EFFECT_CHRISTMAS
//#    define RGBLIGHT_EFFECT_STATIC_GRADIENT
//#    define RGBLIGHT_EFFECT_RGB_TEST
//#    define RGBLIGHT_EFFECT_ALTERNATING
/*== customize breathing effect ==*/
/*==== (DEFAULT) use fixed table instead of exp() and sin() ====*/
//#    define RGBLIGHT_BREATHE_TABLE_SIZE 256      // 256(default) or 128 or 64
/*==== use exp() and sin() ====*/
//#    define RGBLIGHT_EFFECT_BREATHE_CENTER 1.85  // 1 to 2.7
//#    define RGBLIGHT_EFFECT_BREATHE_MAX    255   // 0 to 255
//#endif

/* Debounce reduces chatter (unintended double-presses) - set 0 if debouncing is not needed */
#define DEBOUNCE 5

/* define if matrix has ghost (lacks anti-ghosting diodes) */
//#define MATRIX_HAS_GHOST

/* Mechanical locking support. Use KC_LCAP, KC_LNUM or KC_LSCR instead in keymap */
#define LOCKING_SUPPORT_ENABLE
/* Locking resynchronize hack */
#define LOCKING_RESYNC_ENABLE

/* If defined, GRAVE_ESC will always act as ESC when CTRL is held.
 * This is useful for the Windows task manager shortcut (ctrl+shift+esc).
 */
//#define GRAVE_ESC_CTRL_OVERRIDE

/*
 * Force NKRO
 *
 * Force NKRO (nKey Rollover) to be enabled by default, regardless of the saved
 * state in the bootmagic EEPROM settings. (Note that NKRO must be enabled in the
 * makefile for this to work.)
 *
 * If forced on, NKRO can be disabled via magic key (default = LShift+RShift+N)
 * until the next keyboard reset.
 *
 * NKRO may prevent your keystrokes from being detected in the BIOS, but it is
 * fully operational during normal computer usage.
 *
 * For a less heavy-handed approach, enable NKRO via magic key (LShift+RShift+N)
 * or via bootmagic (hold SPACE+N while plugging in the keyboard). Once set by
 * bootmagic, NKRO mode will always be enabled until it is toggled again during a
 * power-up.
 *
 */
//#define FORCE_NKRO

/*
 * Feature disable options
 *  These options are also useful to firmware size reduction.
 */

/* disable debug print */
//#define NO_DEBUG

/* disable print */
//#define NO_PRINT

/* disable action features */
//#define NO_ACTION_LAYER
//#define NO_ACTION_TAPPING
//#define NO_ACTION_ONESHOT

/* disable these deprecated features by default */
#define NO_ACTION_MACRO
#define NO_ACTION_FUNCTION

/* Bootmagic Lite key configuration */
//#define BOOTMAGIC_LITE_ROW 0
//#define BOOTMAGIC_LITE_COLUMN 0

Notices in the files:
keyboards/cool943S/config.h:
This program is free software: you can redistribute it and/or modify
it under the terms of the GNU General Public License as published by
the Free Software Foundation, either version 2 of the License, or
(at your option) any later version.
